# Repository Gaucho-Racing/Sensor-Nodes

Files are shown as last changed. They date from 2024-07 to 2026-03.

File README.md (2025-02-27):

# Sensor Node hardware and software for GR25

---

## Hardware 
The Hardware is split into a couple of folders and have Kicad projects that relate to the Sensor Nodes. This includes random projects and some hardware that might have been usefull.

---

## Software

Includes software for the Sensor Nodes

### Compilation:

To compile and be able to debug the project you need the following: 
- CMAKE 
- arm-none-eabi-gcc
- openocd
- ninja
- VSCode CMAKE extension
- VSCode Cortex Debug extension

**Make sure cmake, arm tolchian, openocd,and ninja are added to path**

To check the version run: 
- cmake --version
- arm-none-eabi-gcc --version
- openocd --version
- ninja --version

After everything is installed you should be able to follow the VSCode UI to compile and debug.

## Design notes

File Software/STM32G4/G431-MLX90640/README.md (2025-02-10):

See the [git wiki page](https://wiki.gauchoracing.com/books/onboarding/page/git) for a primer on git
# Required stuff
## Applications
Mac and Unix download using package managers (besides arm-toolchain), Windows use links below
* [CMAKE](https://cmake.org/download/)  
* [ARM toolchain (arm-none-eabi), CHECK OS VERSION BEFORE DOWNLOADING](https://developer.arm.com/downloads/-/arm-gnu-toolchain-downloads)  
* [openocd](https://github.com/openocd-org/openocd/releases/tag/v0.12.0)  
* [ninja](https://github.com/ninja-build/ninja/releases)  
## VS Code extensions
* CMAKE  
* Cortex Debug
### Optional VS Code extensions
* Serial Monitor

# How to run
1. Download Required stuff and add to PATH
2. Open VSCode  
3. If the CMake Extension prompts you to set up the configuration, choose DEBUG and proceed to step 5
4. Generate the build stuff with `cmake --preset <target>`. With target in development being `Debug` typically.  
5. Run and Debug, Debug using the provided Debug config, Cortex Debug  
6. Cry as nothing works, then after much debugging rejoice as something works!

# Debugging
If something doesn't work chances are one of the tools wasn't added to path correctly, run each of the tools independently  
* CMAKE - `cmake --version`
* ARM toolchain - `arm-none-eabi-gcc --version`
* openocd - `openocd --version`
* ninja - `ninja --version`

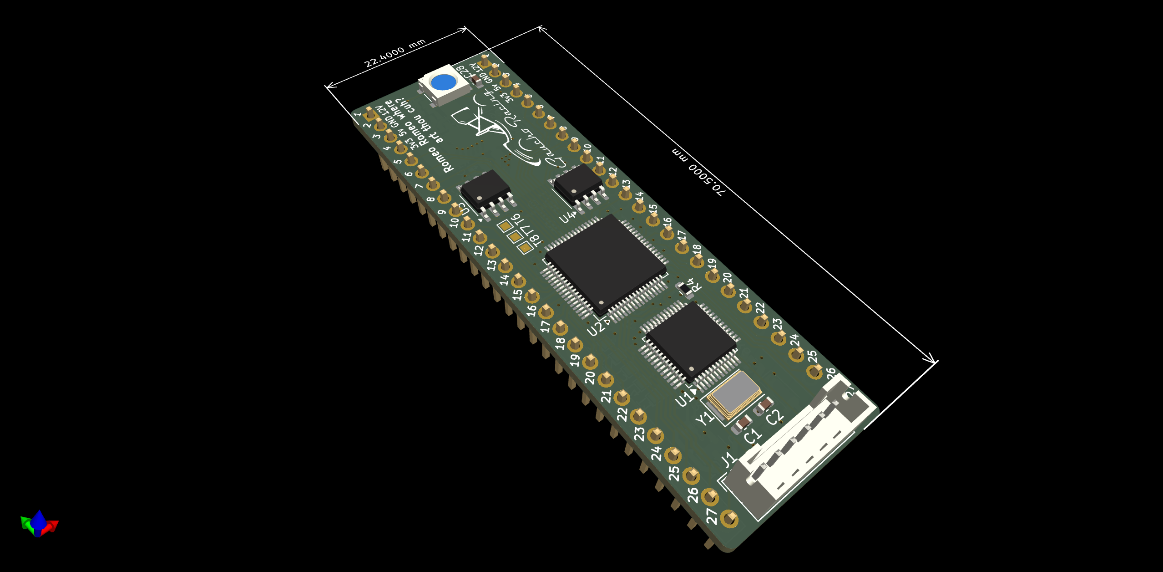
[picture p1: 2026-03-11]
Hardware/Sensor_Nodes_V3/gr25_nodes.png

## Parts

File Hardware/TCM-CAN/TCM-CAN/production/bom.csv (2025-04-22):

Designator | Footprint | Quantity | Value | LCSC Part #
J2, J3 | PinHeader_1x27_P2.54mm_Vertical | 2 | Conn_01x27_Socket
J4 | PinSocket_2x20_P2.54mm_Vertical | 1 | Conn_02x20_Odd_Even
J5 | JST_XH_B6B-XH-A_1x06_P2.50mm_Vertical | 1 | Conn_01x06_Socket

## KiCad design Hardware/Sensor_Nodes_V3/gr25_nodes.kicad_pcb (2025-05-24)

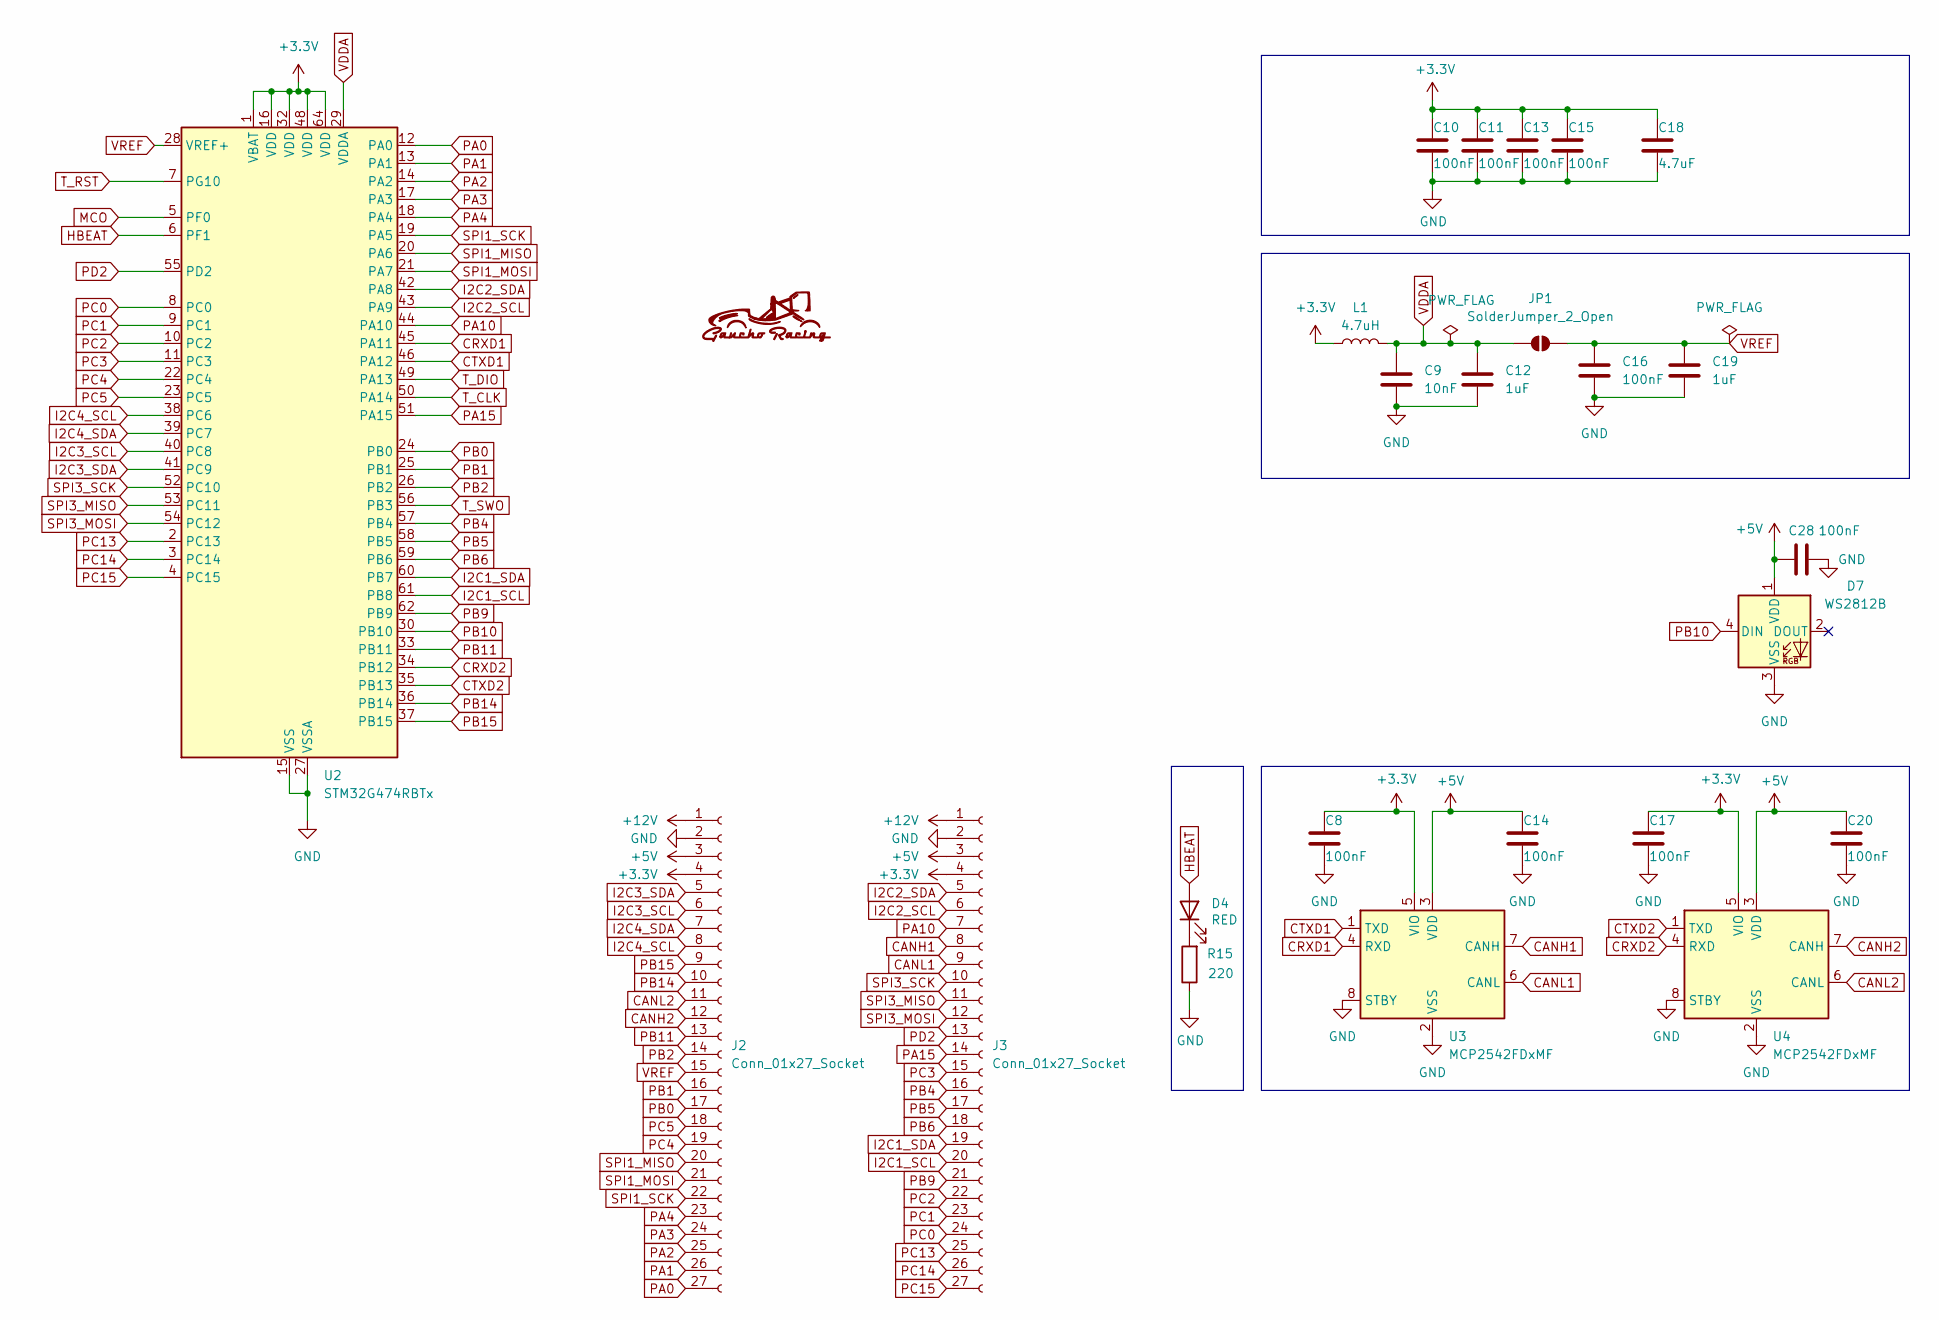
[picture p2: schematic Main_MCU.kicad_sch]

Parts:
C8, C10, C11, C13, C14, C15, C16, C17, C20: 100nF; C_0603_1608Metric; LCSC C14663
C9: 10nF; C_0603_1608Metric; LCSC C57112
C12, C19: 1uF; C_0603_1608Metric; LCSC C15849
C18: 4.7uF; C_0603_1608Metric; LCSC C19666
C28: 100nF; C_0603_1608Metric
D4: RED; LED_0603_1608Metric; LCSC C2286
D7: WS2812B; LED_WS2812B_PLCC4_5.0x5.0mm_P3.2mm
J2, J3: Conn_01x27_Socket; PinHeader_1x27_P2.54mm_Vertical
JP1: SolderJumper_2_Open; SolderJumper-2_P1.3mm_Open_TrianglePad1.0x1.5mm
L1: 4.7uH; C_1206_3216Metric; LCSC C1049
R15: 220; R_0402_1005Metric; LCSC C25091
U2: STM32G474RBTx; LQFP-64_10x10mm_P0.5mm; LCSC C529413
U3, U4: MCP2542FDxMF; SOIC-8_3.9x4.9mm_P1.27mm

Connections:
+3.3V: C8.1, C10.1, C11.1, C13.1, C15.1, C17.1, C18.1, J2.4, J3.4, L1.1, U2.1 (VBAT), U2.16 (VDD), U2.32 (VDD), U2.48 (VDD), U2.64 (VDD), U3.5 (VIO), U4.5 (VIO); also elsewhere on the board
+5V: C14.1, C20.1, C28.2, D7.1 (VDD), J2.3, J3.3, U3.3 (VDD), U4.3 (VDD); also elsewhere on the board
+12V: J2.1, J3.1; also elsewhere on the board
CANH1: J3.8, U3.7 (CANH)
CANH2: J2.12, U4.7 (CANH)
CANL1: J3.9, U3.6 (CANL)
CANL2: J2.11, U4.6 (CANL)
CRXD1: U2.45 (PA11), U3.4 (RXD)
CRXD2: U2.34 (PB12), U4.4 (RXD)
CTXD1: U2.46 (PA12), U3.1 (TXD)
CTXD2: U2.35 (PB13), U4.1 (TXD)
GND: C8.2, C9.2, C10.2, C11.2, C12.2, C13.2, C14.2, C15.2, C16.2, C17.2, C18.2, C19.2, C20.2, C28.1, D7.3 (VSS), J2.2, J3.2, R15.1, U2.15 (VSS), U2.27 (VSSA), U2.31 (VSS), U2.47 (VSS), U2.63 (VSS), U3.2 (VSS), U3.8 (STBY), U3.9 (VSS), U4.2 (VSS), U4.8 (STBY), U4.9 (VSS); also elsewhere on the board
HBEAT: D4.2 (A), U2.6 (PF1)
I2C1_SCL: J3.20, U2.61 (PB8)
I2C1_SDA: J3.19, U2.60 (PB7)
I2C2_SCL: J3.6, U2.43 (PA9)
I2C2_SDA: J3.5, U2.42 (PA8)
I2C3_SCL: J2.6, U2.40 (PC8)
I2C3_SDA: J2.5, U2.41 (PC9)
I2C4_SCL: J2.8, U2.38 (PC6)
I2C4_SDA: J2.7, U2.39 (PC7)
MCO: U2.5 (PF0); also elsewhere on the board
unnamed: D4.1 (K), R15.2
PA0: J2.27, U2.12 (PA0)
PA1: J2.26, U2.13 (PA1)
PA2: J2.25, U2.14 (PA2)
PA3: J2.24, U2.17 (PA3)
PA4: J2.23, U2.18 (PA4)
PA10: J3.7, U2.44 (PA10)
PA15: J3.14, U2.51 (PA15)
PB0: J2.17, U2.24 (PB0)
PB1: J2.16, U2.25 (PB1)
PB2: J2.14, U2.26 (PB2)
PB4: J3.16, U2.57 (PB4)
PB5: J3.17, U2.58 (PB5)
PB6: J3.18, U2.59 (PB6)
PB9: J3.21, U2.62 (PB9)
PB10: D7.4 (DIN), U2.30 (PB10)
PB11: J2.13, U2.33 (PB11)
PB14: J2.10, U2.36 (PB14)
PB15: J2.9, U2.37 (PB15)
PC0: J3.24, U2.8 (PC0)
PC1: J3.23, U2.9 (PC1)
PC2: J3.22, U2.10 (PC2)
PC3: J3.15, U2.11 (PC3)
PC4: J2.19, U2.22 (PC4)
PC5: J2.18, U2.23 (PC5)
PC13: J3.25, U2.2 (PC13)
PC14: J3.26, U2.3 (PC14)
PC15: J3.27, U2.4 (PC15)
PD2: J3.13, U2.55 (PD2)
SPI1_MISO: J2.20, U2.20 (PA6)
SPI1_MOSI: J2.21, U2.21 (PA7)
SPI1_SCK: J2.22, U2.19 (PA5)
SPI3_MISO: J3.11, U2.53 (PC11)
SPI3_MOSI: J3.12, U2.54 (PC12)
SPI3_SCK: J3.10, U2.52 (PC10)
T_CLK: U2.50 (PA14); also elsewhere on the board
T_DIO: U2.49 (PA13); also elsewhere on the board
T_RST: U2.7 (PG10); also elsewhere on the board
T_SWO: U2.56 (PB3); also elsewhere on the board
VDDA: C9.1, C12.1, JP1.1 (A), L1.2, U2.29 (VDDA)
VREF: C16.1, C19.1, J2.15, JP1.2 (B), U2.28 (VREF+)

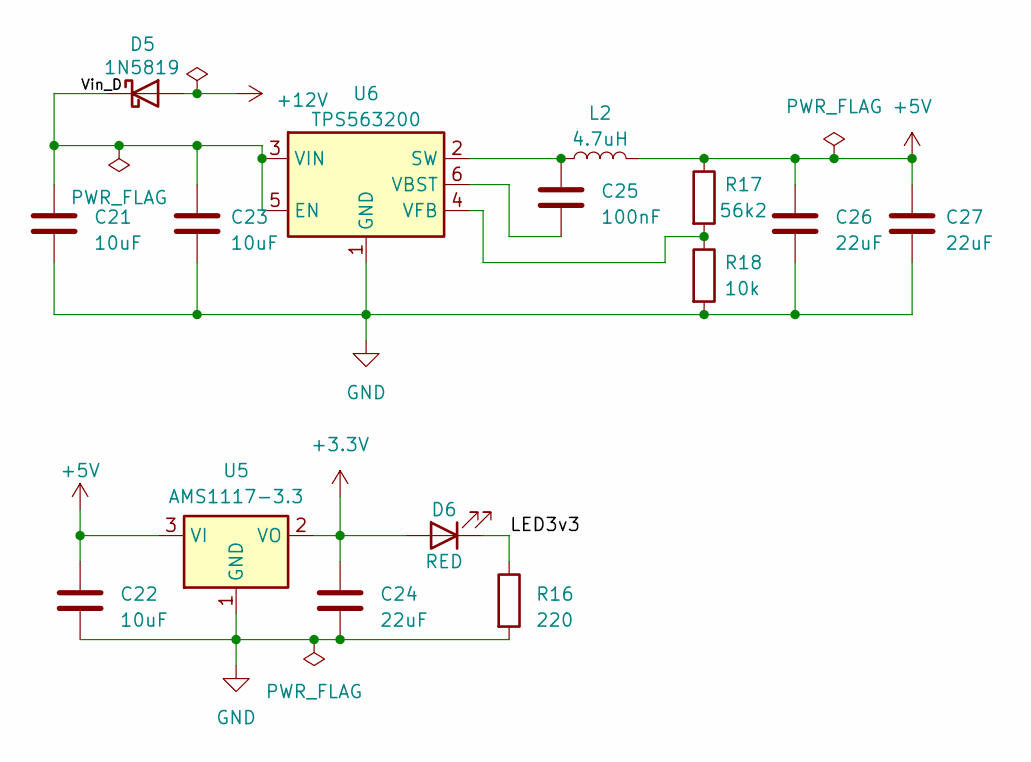
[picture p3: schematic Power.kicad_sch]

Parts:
C21, C22, C23: 10uF; C_0805_2012Metric; LCSC C15850
C24, C26, C27: 22uF; C_0805_2012Metric; LCSC C45783
C25: 100nF; C_0603_1608Metric; LCSC C14663
D5: 1N5819; D_SOD-323_HandSoldering; LCSC C191023
D6: RED; LED_0603_1608Metric; LCSC C2286
L2: 4.7uH; L_Cenker_CKCS6020; LCSC C5291878
R16: 220; R_0402_1005Metric; LCSC C25091
R17: 56k2; R_0402_1005Metric; LCSC C25796
R18: 10k; R_0402_1005Metric; LCSC C25744
U5: AMS1117-3.3; SOT-223-3_TabPin2; LCSC C6186
U6: TPS563200; SOT-23-6; LCSC C97253

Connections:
+3.3V: C24.1, D6.2 (A), U5.2 (VO); also elsewhere on the board
+5V: C22.1, C26.1, C27.1, L2.2, R17.1, U5.3 (VI); also elsewhere on the board
+12V: D5.2 (A); also elsewhere on the board
/Power/LED3v3: D6.1 (K), R16.1
/Power/Vin_D: C21.1, C23.1, D5.1 (K), U6.3 (VIN), U6.5 (EN)
GND: C21.2, C22.2, C23.2, C24.2, C26.2, C27.2, R16.2, R18.2, U5.1 (GND), U6.1 (GND); also elsewhere on the board
unnamed: C25.1, L2.1, U6.2 (SW)
unnamed: C25.2, U6.6 (VBST)
unnamed: R17.2, R18.1, U6.4 (VFB)

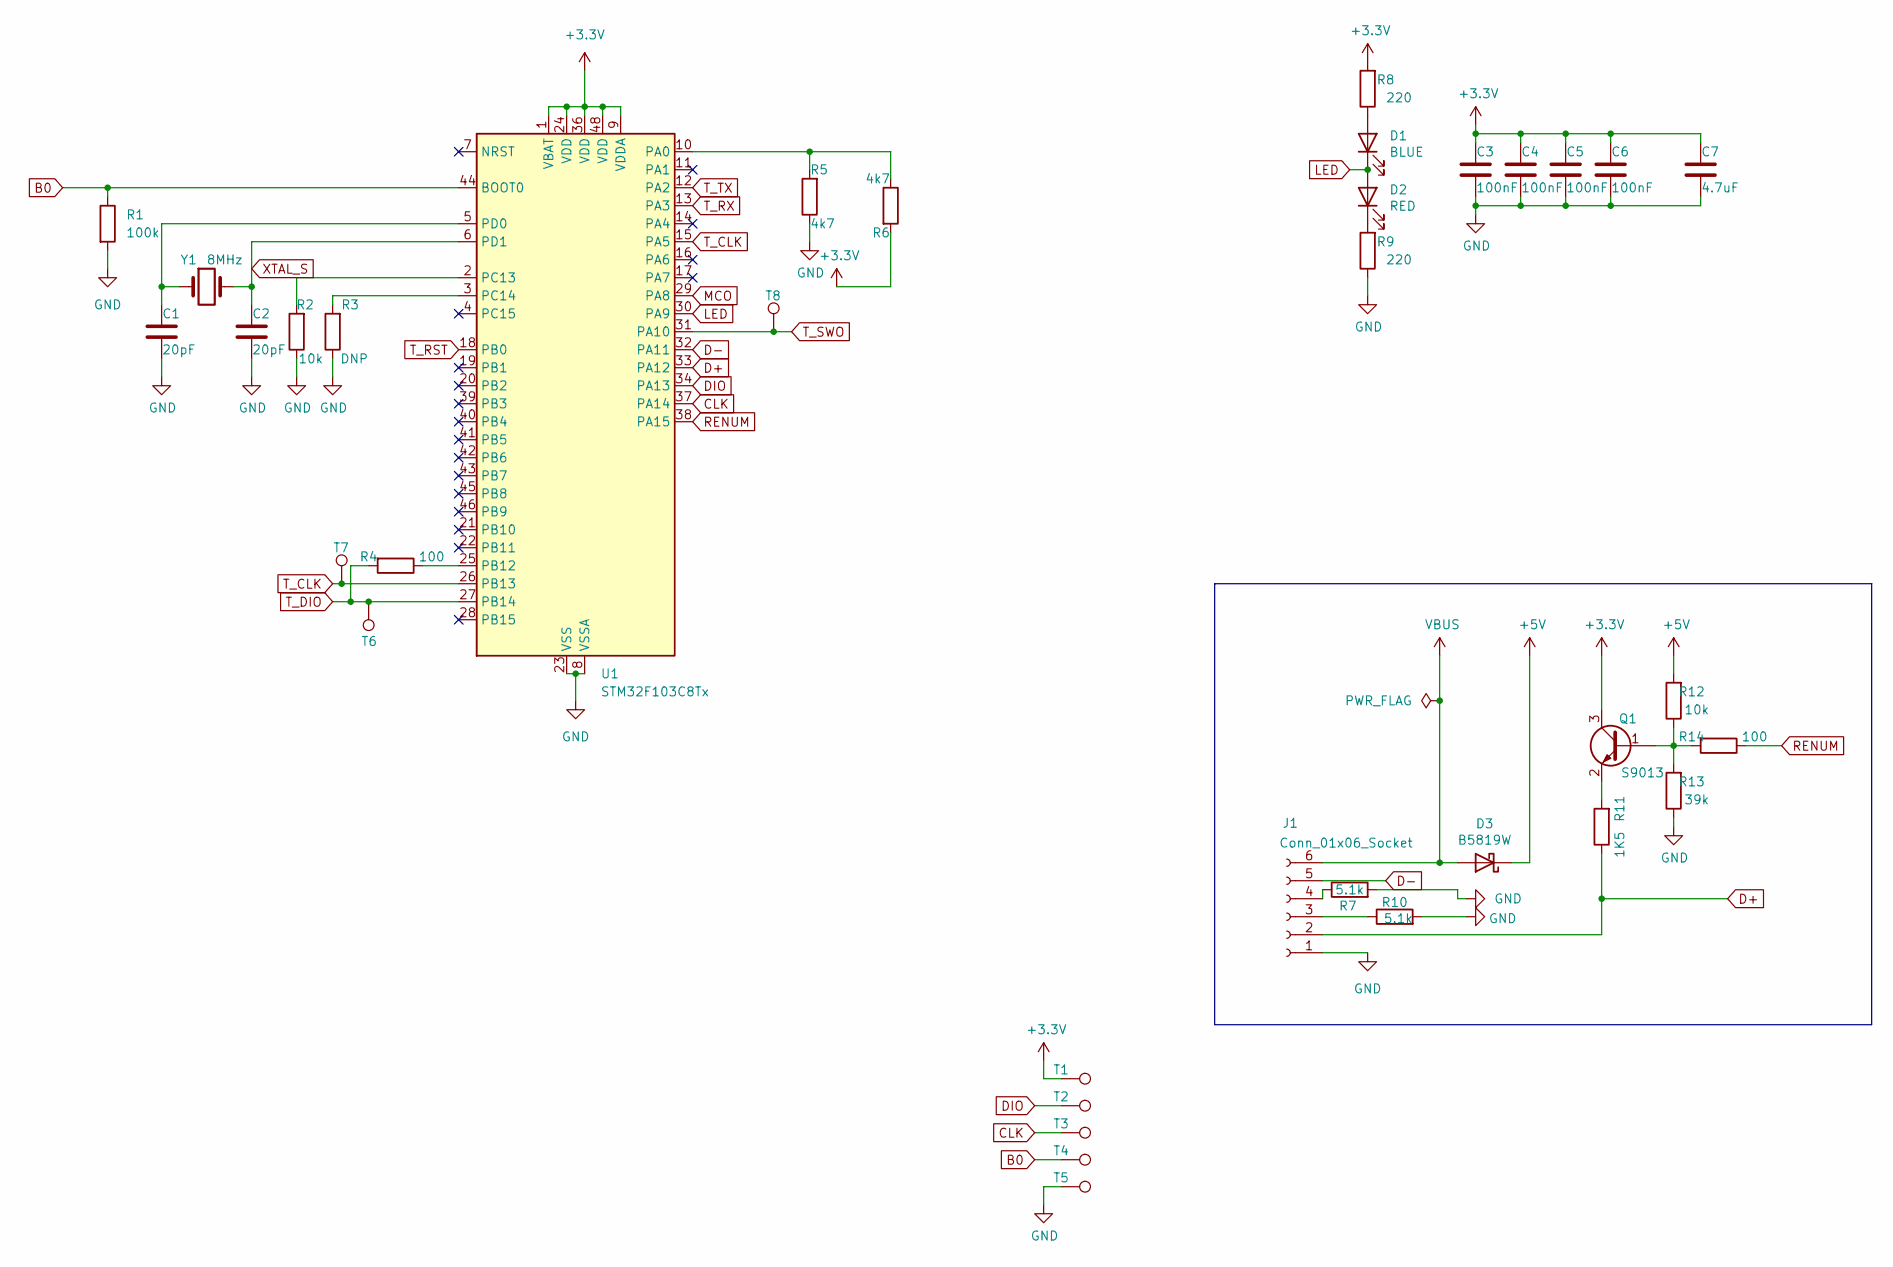
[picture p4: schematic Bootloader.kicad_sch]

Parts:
C1, C2: 20pF; C_0603_1608Metric; LCSC C1648
C3, C4, C5, C6: 100nF; C_0603_1608Metric; LCSC C14663
C7: 4.7uF; C_0603_1608Metric; LCSC C19666
D1: BLUE; LED_0603_1608Metric; LCSC C2290
D2: RED; LED_0603_1608Metric; LCSC C2286
D3: B5819W; D_SOD-123; LCSC C8598
J1: Conn_01x06_Socket; JST_PH_B6B-PH-K_1x06_P2.00mm_Vertical
Q1: S9013; SOT-23; LCSC C6749
R1: 100k; R_0402_1005Metric; LCSC C25741
R2, R12: 10k; R_0402_1005Metric; LCSC C25744
R3: DNP; R_0402_1005Metric; LCSC xxC25744
R4: 100; R_0603_1608Metric; LCSC C22775
R5, R6: 4k7; R_0402_1005Metric; LCSC C25900
R7, R10: 5.1k; R_0402_1005Metric; LCSC C25905
R8, R9: 220; R_0402_1005Metric; LCSC C25091
R11: 1K5; R_0402_1005Metric; LCSC C25867
R13: 39k; R_0402_1005Metric; LCSC C25783
R14: 100; R_0402_1005Metric; LCSC C25076
T1, T2, T3, T4, T5, T6, T7, T8: TestPoint_Pad_1.0x1.0mm
U1: STM32F103C8Tx; LQFP-48_7x7mm_P0.5mm; LCSC C8734
Y1: 8MHz; Crystal_SMD_5032-2Pin_5.0x3.2mm; LCSC C115962

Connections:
+3.3V: C3.1, C4.1, C5.1, C6.1, C7.1, Q1.3 (C), R6.2, R8.2, T1.1, U1.1 (VBAT), U1.9 (VDDA), U1.24 (VDD), U1.36 (VDD), U1.48 (VDD); also elsewhere on the board
+5V: D3.1 (K), R12.2; also elsewhere on the board
B0: R1.1, T4.1, U1.44 (BOOT0)
CLK: T3.1, U1.37 (PA14)
D+: J1.2, R11.1, U1.33 (PA12)
D-: J1.5, U1.32 (PA11)
DIO: T2.1, U1.34 (PA13)
GND: C1.2, C2.2, C3.2, C4.2, C5.2, C6.2, C7.2, J1.1, R1.2, R2.1, R3.1, R5.1, R7.2, R9.1, R10.2, R13.1, T5.1, U1.8 (VSSA), U1.23 (VSS), U1.35 (VSS), U1.47 (VSS); also elsewhere on the board
LED: D1.1 (K), D2.2 (A), U1.30 (PA9)
MCO: U1.29 (PA8); also elsewhere on the board
unnamed: D1.2 (A), R8.1
unnamed: D2.1 (K), R9.2
unnamed: J1.3, R10.1
unnamed: J1.4, R7.1
unnamed: Q1.1 (B), R12.1, R13.2, R14.2
unnamed: Q1.2 (E), R11.2
unnamed: R5.2, R6.1, U1.10 (PA0)
unnamed: R4.1, U1.25 (PB12)
unnamed: R2.2, U1.2 (PC13)
unnamed: R3.2, U1.3 (PC14)
unnamed: C1.1, U1.5 (PD0), Y1.1
RENUM: R14.1, U1.38 (PA15)
T_CLK: T7.1, U1.15 (PA5), U1.26 (PB13); also elsewhere on the board
T_DIO: R4.2, T6.1, U1.27 (PB14); also elsewhere on the board
T_RST: U1.18 (PB0); also elsewhere on the board
T_RX: U1.13 (PA3)
T_SWO: T8.1, U1.31 (PA10); also elsewhere on the board
T_TX: U1.12 (PA2)
VBUS: D3.2 (A), J1.6
XTAL_S: C2.1, U1.6 (PD1), Y1.2

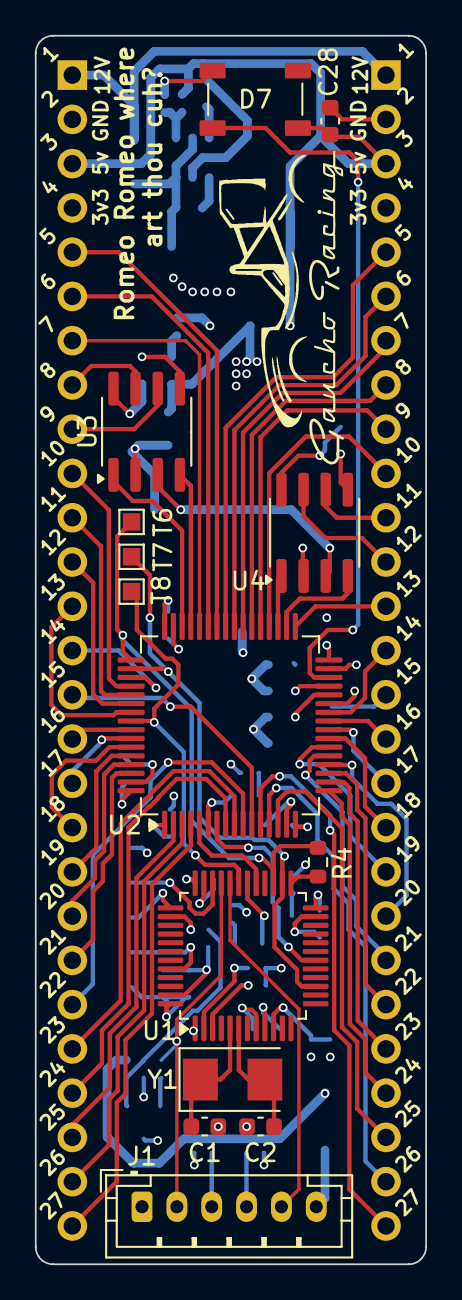
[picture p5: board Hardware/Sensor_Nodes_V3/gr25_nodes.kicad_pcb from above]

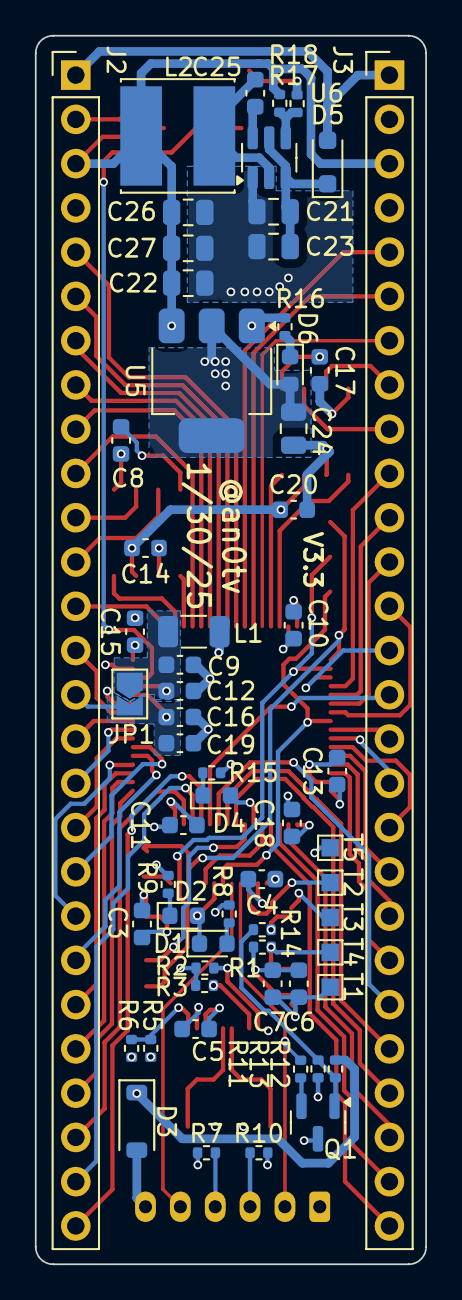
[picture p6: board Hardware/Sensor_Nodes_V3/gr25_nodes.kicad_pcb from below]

Board: 4 copper layers, 22.4 x 70.5 mm, 75 parts (61 on the bottom side), 88 nets.

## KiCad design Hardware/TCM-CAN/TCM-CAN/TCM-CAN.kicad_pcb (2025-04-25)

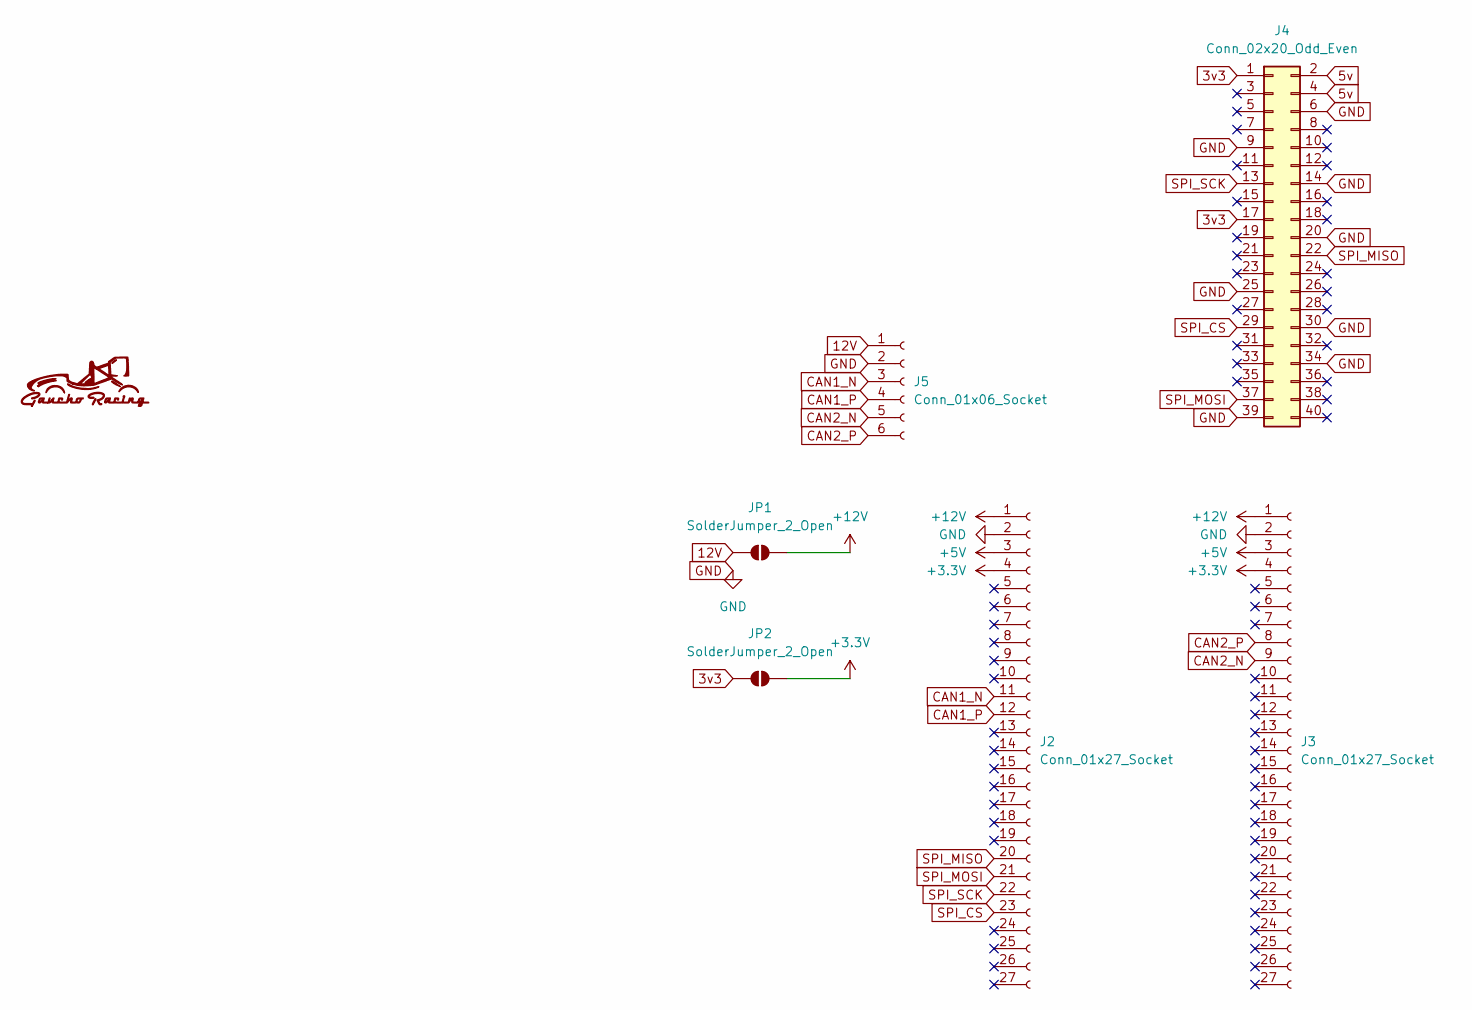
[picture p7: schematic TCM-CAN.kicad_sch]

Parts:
J2, J3: Conn_01x27_Socket; PinHeader_1x27_P2.54mm_Vertical
J4: Conn_02x20_Odd_Even; PinSocket_2x20_P2.54mm_Vertical
J5: Conn_01x06_Socket; JST_XH_B6B-XH-A_1x06_P2.50mm_Vertical
JP1, JP2: SolderJumper_2_Open; SolderJumper-2_P1.3mm_Open_Pad1.0x1.5mm

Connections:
3v3: J4.1, J4.17, JP2.1 (A)
5v: J4.2, J4.4
12V: J5.1, JP1.1 (A)
+3.3V: J2.4, J3.4, JP2.2 (B)
+5V: J2.3, J3.3
+12V: J2.1, J3.1, JP1.2 (B)
CAN1_N: J2.11, J5.3
CAN1_P: J2.12, J5.4
CAN2_N: J3.9, J5.5
CAN2_P: J3.8, J5.6
GND: J2.2, J3.2, J4.6, J4.9, J4.14, J4.20, J4.25, J4.30, J4.34, J4.39, J5.2
SPI_CS: J2.23, J4.29
SPI_MISO: J2.20, J4.22
SPI_MOSI: J2.21, J4.37
SPI_SCK: J2.22, J4.13

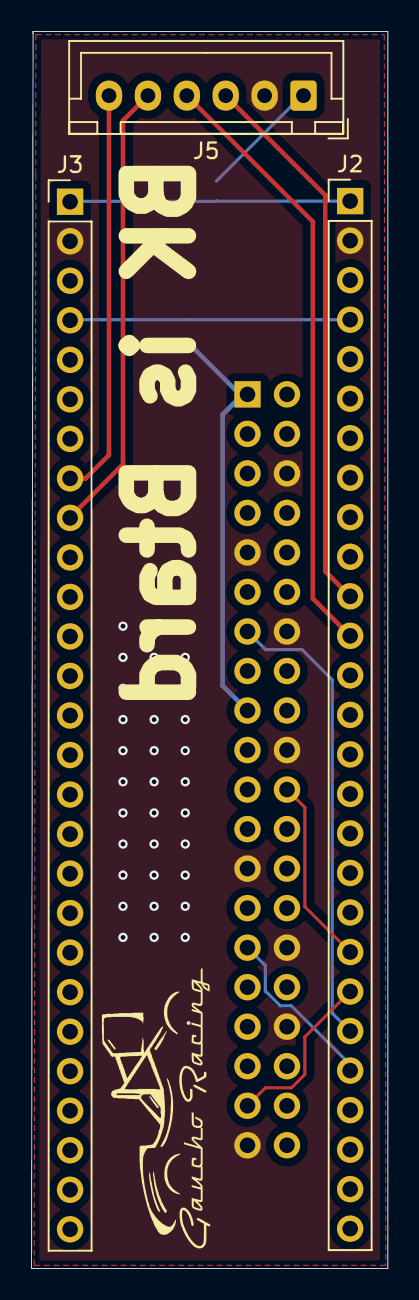
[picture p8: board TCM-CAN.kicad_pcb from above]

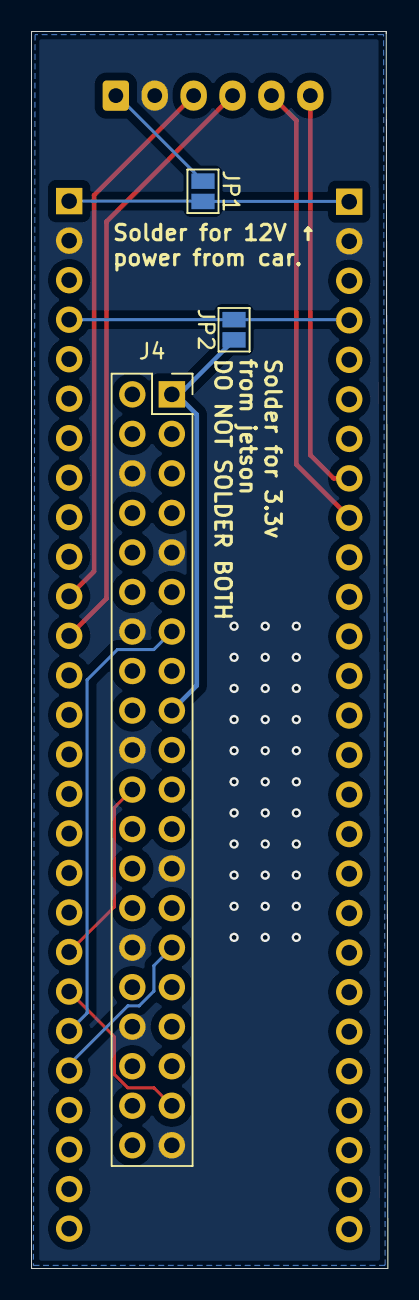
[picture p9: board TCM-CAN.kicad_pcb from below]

Board: 2 copper layers, 22.9 x 79.5 mm, 6 parts (3 on the bottom side), 15 nets.

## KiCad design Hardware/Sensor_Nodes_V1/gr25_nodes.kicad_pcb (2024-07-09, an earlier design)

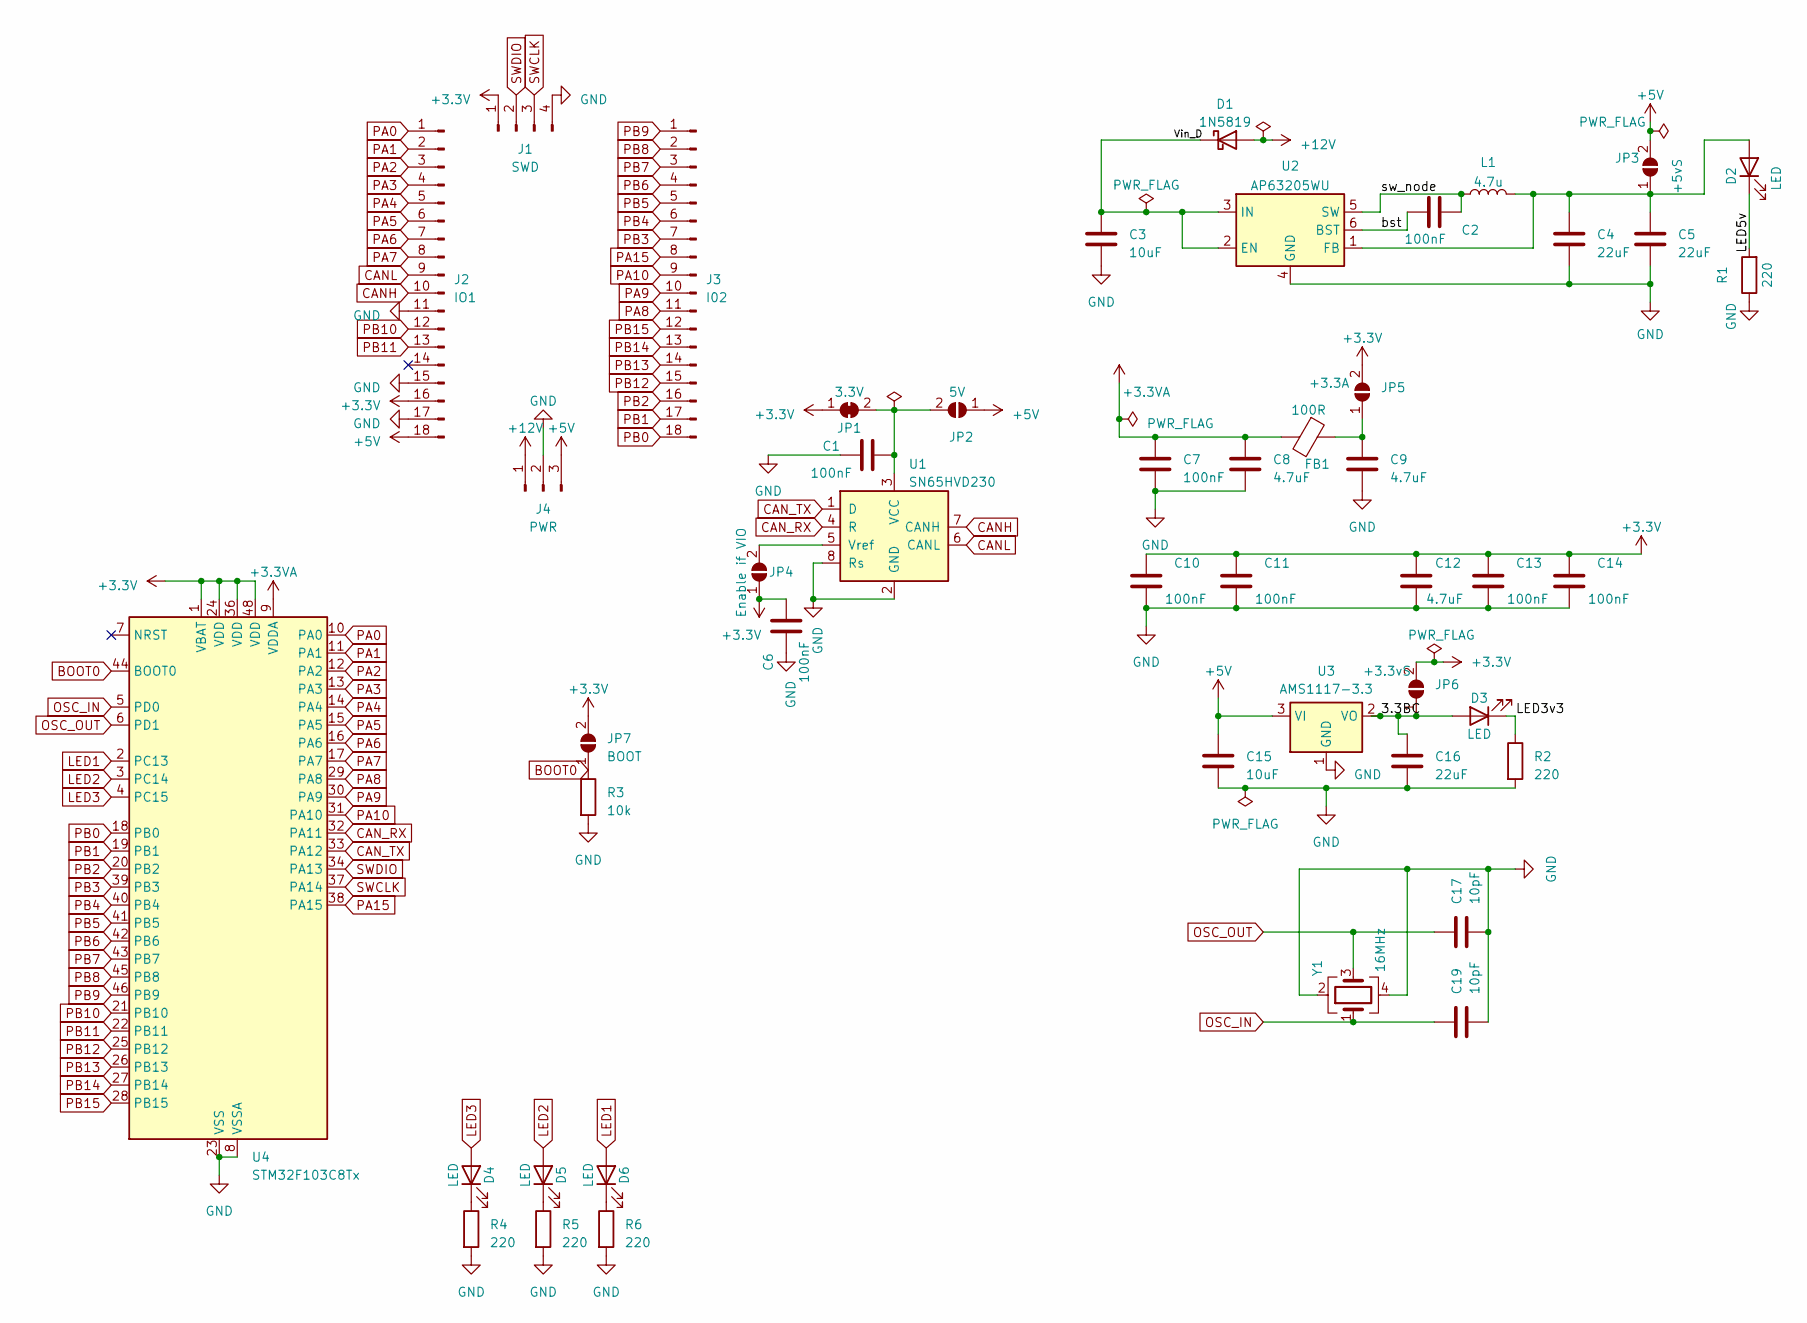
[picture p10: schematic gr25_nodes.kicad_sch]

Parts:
C1, C2, C6, C7, C10, C11, C13, C14: 100nF; C_0603_1608Metric; LCSC C14663
C3: 10uF; C_0805_2012Metric; LCSC C440198
C4, C5, C16: 22uF; C_1206_3216Metric; LCSC C12891
C8, C9, C12: 4.7uF; C_0603_1608Metric; LCSC C19666
C15: 10uF; C_0603_1608Metric; LCSC C96446
C17, C19: 10pF; C_0603_1608Metric; LCSC C1634
D1: 1N5819; D_SOD-323_HandSoldering; LCSC C191023
D2, D3, D4, D5, D6: LED; D_0603_1608Metric; LCSC C2286
FB1: 100R; L_0805_2012Metric; LCSC C1015
J1: SWD; PinHeader_1x04_P2.54mm_Vertical
J2: IO1; PinHeader_1x18_P2.54mm_Vertical
J3: I02; PinHeader_1x18_P2.54mm_Vertical
J4: PWR; PinHeader_1x03_P2.54mm_Vertical
JP1: 3.3V; SolderJumper-2_P1.3mm_Bridged_RoundedPad1.0x1.5mm
JP2: 5V; SolderJumper-2_P1.3mm_Open_RoundedPad1.0x1.5mm
JP3: +5vS; SolderJumper-2_P1.3mm_Open_RoundedPad1.0x1.5mm
JP4: Enable if VIO; SolderJumper-2_P1.3mm_Open_RoundedPad1.0x1.5mm
JP5: +3.3A; SolderJumper-2_P1.3mm_Open_RoundedPad1.0x1.5mm
JP6: +3.3vS; SolderJumper-2_P1.3mm_Open_RoundedPad1.0x1.5mm
JP7: BOOT; SolderJumper-2_P1.3mm_Open_RoundedPad1.0x1.5mm
L1: 4.7u; L_Bourns-SRN4018; PARTNUM SRN4018-4R7M
R1, R2, R4, R5, R6: 220; R_0603_1608Metric; LCSC C22962
R3: 10k; R_0603_1608Metric; LCSC C25804
U1: SN65HVD230; SOIC-8_3.9x4.9mm_P1.27mm; LCSC C12084
U2: AP63205WU; TSOT-23-6; PARTNUM AP63205WU
U3: AMS1117-3.3; SOT-223-3_TabPin2; LCSC C6186
U4: STM32F103C8Tx; LQFP-48_7x7mm_P0.5mm; LCSC C8734
Y1: 16MHz; Crystal_SMD_3225-4Pin_3.2x2.5mm; LCSC C13738

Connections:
+3.3V: C6.1, C10.1, C11.1, C12.1, C13.1, C14.1, J1.1, J2.16, JP1.1 (A), JP4.1 (A), JP5.2 (B), JP6.2 (B), JP7.2 (B), U4.1 (VBAT), U4.24 (VDD), U4.36 (VDD), U4.48 (VDD)
+3.3VA: C7.1, C8.1, FB1.2, U4.9 (VDDA)
+5V: C15.1, J2.18, J4.3, JP2.1 (A), JP3.2 (B), U3.3 (VI)
+12V: D1.2 (A), J4.1
/3.3BC: C16.1, D3.2 (A), JP6.1 (A), U3.2 (VO)
/LED3v3: D3.1 (K), R2.1
/LED5v: D2.1 (K), R1.2
/Vin_D: C3.1, D1.1 (K), U2.2 (EN), U2.3 (IN)
/bst: C2.1, U2.6 (BST)
/sw_node: C2.2, L1.1, U2.5 (SW)
BOOT0: JP7.1 (A), R3.1, U4.44 (BOOT0)
CANH: J2.10, U1.7 (CANH)
CANL: J2.9, U1.6 (CANL)
CAN_RX: U1.4 (R), U4.32 (PA11)
CAN_TX: U1.1 (D), U4.33 (PA12)
GND: C1.2, C3.2, C4.2, C5.2, C6.2, C7.2, C8.2, C9.2, C10.2, C11.2, C12.2, C13.2, C14.2, C15.2, C16.2, C17.2, C19.2, J1.4, J2.11, J2.15, J2.17, J4.2, R1.1, R2.2, R3.2, R4.2, R5.2, R6.2, U1.2 (GND), U1.8 (Rs), U2.4 (GND), U3.1 (GND), U4.8 (VSSA), U4.23 (VSS), U4.35 (VSS), U4.47 (VSS), Y1.2, Y1.4
LED1: D6.2 (A), U4.2 (PC13)
LED2: D5.2 (A), U4.3 (PC14)
LED3: D4.2 (A), U4.4 (PC15)
unnamed: C1.1, JP1.2 (B), JP2.2 (B), U1.3 (VCC)
unnamed: C4.1, C5.1, D2.2 (A), JP3.1 (A), L1.2, U2.1 (FB)
unnamed: D4.1 (K), R4.1
unnamed: D5.1 (K), R5.1
unnamed: D6.1 (K), R6.1
unnamed: JP4.2 (B), U1.5 (Vref)
unnamed: C9.1, FB1.1, JP5.1 (A)
OSC_IN: C19.1, U4.5 (PD0), Y1.1
OSC_OUT: C17.1, U4.6 (PD1), Y1.3
PA0: J2.1, U4.10 (PA0)
PA1: J2.2, U4.11 (PA1)
PA2: J2.3, U4.12 (PA2)
PA3: J2.4, U4.13 (PA3)
PA4: J2.5, U4.14 (PA4)
PA5: J2.6, U4.15 (PA5)
PA6: J2.7, U4.16 (PA6)
PA7: J2.8, U4.17 (PA7)
PA8: J3.11, U4.29 (PA8)
PA9: J3.10, U4.30 (PA9)
PA10: J3.9, U4.31 (PA10)
PA15: J3.8, U4.38 (PA15)
PB0: J3.18, U4.18 (PB0)
PB1: J3.17, U4.19 (PB1)
PB2: J3.16, U4.20 (PB2)
PB3: J3.7, U4.39 (PB3)
PB4: J3.6, U4.40 (PB4)
PB5: J3.5, U4.41 (PB5)
PB6: J3.4, U4.42 (PB6)
PB7: J3.3, U4.43 (PB7)
PB8: J3.2, U4.45 (PB8)
PB9: J3.1, U4.46 (PB9)
PB10: J2.12, U4.21 (PB10)
PB11: J2.13, U4.22 (PB11)
PB12: J3.15, U4.25 (PB12)
PB13: J3.14, U4.26 (PB13)
PB14: J3.13, U4.27 (PB14)
PB15: J3.12, U4.28 (PB15)
SWCLK: J1.3, U4.37 (PA14)
SWDIO: J1.2, U4.34 (PA13)

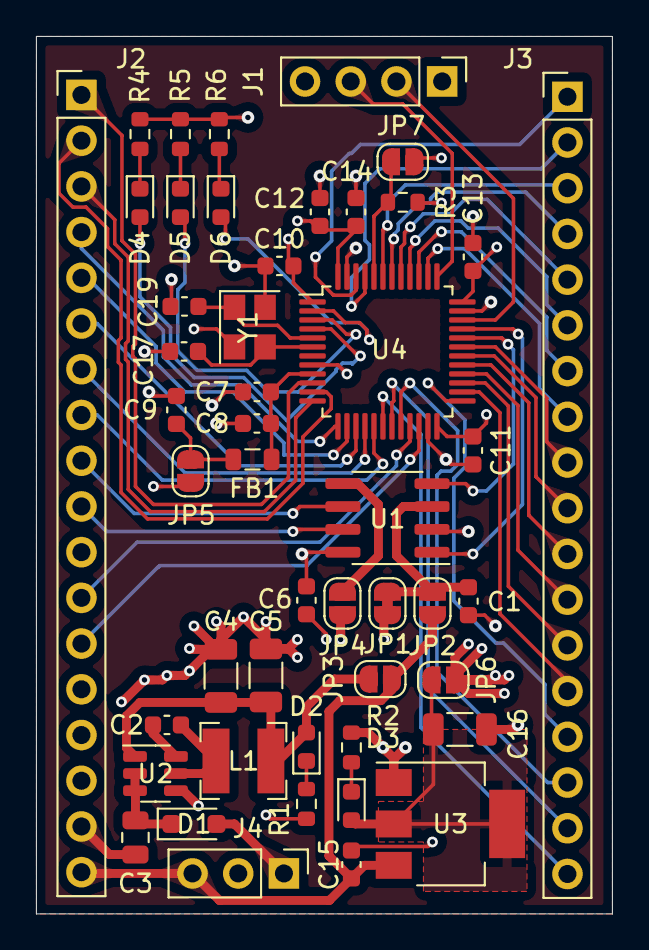
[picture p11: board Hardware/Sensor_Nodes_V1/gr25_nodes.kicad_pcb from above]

Board: 4 copper layers, 32.0 x 48.8 mm, 48 parts (0 on the bottom side), 58 nets.

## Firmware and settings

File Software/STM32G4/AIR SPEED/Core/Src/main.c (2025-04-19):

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
/* Includes ------------------------------------------------------------------*/
#include "main.h"
#include "crc.h"
#include "fdcan.h"
#include "i2c.h"
#include "spi.h"
#include "gpio.h"


/* USER CODE BEGIN Includes */
#include <stdio.h>
#include <math.h>
// #include "VL53L4ED_api.h"
#include "Aspeed.h"
//#include "circularBuffer.h"
/* USER CODE END Includes */

/* USER CODE BEGIN PD */
#ifdef __GNUC__
#define PUTCHAR_PROTOTYPE int __io_putchar(int ch)
#else
#define PUTCHAR_PROTOTYPE int fputc(int ch, FILE *f)
#endif
/* USER CODE END PD */

/* USER CODE BEGIN PM */
PUTCHAR_PROTOTYPE
{
  ITM_SendChar(ch);
  return ch;
}
//CircularBuffer *cb;
/* USER CODE END PM */


/* USER CODE BEGIN PV */
// FDCAN_RxHeaderTypeDef RxHeader_FDCAN2;
/* USER CODE END PV */

void SystemClock_Config(void);
/* USER CODE BEGIN 0 */
/*
I2C2 - is meant for thermal sensor MLX90640 and is ran using DMA to offload CPU for calculations
     - still need to fully test but ideally implmentation is done


 */
/* USER CODE END 0 */

/**
  * @brief  The application entry point.
  * @retval int
  */
int main(void)
{

  /* USER CODE BEGIN 1 */
  //cb = circular_buffer_init(64, 68 * sizeof(uint8_t));
  /* USER CODE END 1 */

  /* MCU Configuration--------------------------------------------------------*/

  /* Reset of all peripherals, Initializes the Flash interface and the Systick. */
  HAL_Init();

  /* Configure the system clock */
  SystemClock_Config();

  /* Initialize all configured peripherals */
  MX_GPIO_Init();
  MX_CRC_Init();
  MX_FDCAN1_Init();
  MX_FDCAN2_Init();
  MX_I2C1_Init();
  MX_SPI3_Init();
  /* USER CODE BEGIN 2 */
  
  // HAL_FDCAN_Start(&hfdcan1);
  // HAL_FDCAN_Start(&hfdcan2);
  // HAL_FDCAN_ActivateNotification(&hfdcan1, FDCAN_IT_RX_FIFO0_NEW_MESSAGE, 0);
  // HAL_FDCAN_ActivateNotification(&hfdcan2, FDCAN_IT_RX_FIFO0_NEW_MESSAGE, 0);

  
  // static uint16_t eeMLX90640[832];
  // static paramsMLX90640 mlx90640;
  // #define MLX90640_ADDRESS 0x33<<1
  // MLX90640_DumpEE(MLX90640_ADDRESS, eeMLX90640);
  
  // MLX90640_ExtractParameters(eeMLX90640, &mlx90640);
  
  // MLX90640_SetRefreshRate(MLX90640_ADDRESS, 0x05);

  // MLX90640_SynchFrame(MLX90640_ADDRESS);
  //  MLX90640_SetRefreshRate(0x33, 0x05);
  /* USER CODE END 2 */

  /* Infinite loop */
  /* USER CODE BEGIN WHILE */
  HAL_GPIO_WritePin(GPIOB, GPIO_PIN_1, GPIO_PIN_RESET); //TOF_L_XSHUT_Pin
  HAL_GPIO_WritePin(GPIOF, GPIO_PIN_1, GPIO_PIN_RESET); //TOF_C_XSHUT_Pin
  HAL_Delay(100); // wait for 5ms to reset the device
  HAL_GPIO_WritePin(GPIOB, GPIO_PIN_1, GPIO_PIN_SET); //TOF_L_XSHUT_Pin
  HAL_GPIO_WritePin(GPIOF, GPIO_PIN_1, GPIO_PIN_SET); //TOF_C_XSHUT_Pin
  HAL_Delay(100); // wait for 5ms to power up the device
  float data[2] = {0};
  

  while (1)
  { 
    // HAL_FDCAN_AddMessageToTxFifoQ(&hfdcan1, &TxHeader, TxData);
    // HAL_FDCAN_AddMessageToTxFifoQ(&hfdcan2, &TxHeader, TxData);
    /* USER CODE END WHILE */

    /* USER CODE BEGIN 3 */
    HAL_Delay(10);
    ASpeedRead(data);
    
    // printf("Pressure * 10000: %d, Temp * 100: %d\n", data[0] + 159, data[1]);
    float air_density = (101693.25)/(287.05*(data[1] + 273.15)); // p/(RT)
    float air_speed = sqrtf((2 * 6894.76 * (fabsf(data[0] + 0.0156f)))/air_density);
    int16_t lazy_air = (int16_t)(air_speed * 100);
    if(data[0] >= 0.0){
      printf("%d\n", (int16_t)(air_speed * 100));
    } else {
      printf("%d\n", -1 * (int16_t)(air_speed * 100));
    }
    // printf("%d\n", lazy_air);
   
    
    
  }
  /* USER CODE END 3 */
}

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
/* USER CODE BEGIN 4 */
// void HAL_FDCAN_RxFifo0Callback(FDCAN_HandleTypeDef *hfdcan, uint32_t RxFifo0ITs)
// {
//   uint8_t RxData[64];
//   HAL_FDCAN_GetRxMessage(hfdcan, FDCAN_RX_FIFO0, &RxHeader_FDCAN2, RxData);
//   printf("got messgae\n");
//   //circularBufferPush(cb, RxData, sizeof(RxData));


// }
/* USER CODE END 4 */

/**
  * @brief  Period elapsed callback in non blocking mode
  * @note   This function is called  when TIM1 interrupt took place, inside
  * HAL_TIM_IRQHandler(). It makes a direct call to HAL_IncTick() to increment
  * a global variable "uwTick" used as application time base.
  * @param  htim : TIM handle
  * @retval None
  */
void HAL_TIM_PeriodElapsedCallback(TIM_HandleTypeDef *htim)
{
  if (htim->Instance == TIM1) {
    HAL_IncTick();
  }
}

/**
  * @brief  This function is executed in case of error occurrence.
  * @retval None
  */
void Error_Handler(void)
{
  /* USER CODE BEGIN Error_Handler_Debug */
  /* User can add his own implementation to report the HAL error return state */
  __disable_irq();
  while (1)
  {
  }
  /* USER CODE END Error_Handler_Debug */
}

#ifdef  USE_FULL_ASSERT
/**
  * @brief  Reports the name of the source file and the source line number
  *         where the assert_param error has occurred.
  * @param  file: pointer to the source file name
  * @param  line: assert_param error line source number
  * @retval None
  */
void assert_failed(uint8_t *file, uint32_t line)
{
  /* USER CODE BEGIN 6 */
  /* User can add his own implementation to report the file name and line number,
     ex: printf("Wrong parameters value: file %s on line %d\r\n", file, line) */
  /* USER CODE END 6 */
}
#endif /* USE_FULL_ASSERT */

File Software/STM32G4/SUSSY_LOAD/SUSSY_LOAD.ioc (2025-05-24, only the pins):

Mcu.UserName=STM32G474RETx
PA0.Signal=ADC1_IN1
PA13.Signal=SYS_JTMS-SWDIO
PA14.Signal=SYS_JTCK-SWCLK
PA5.Signal=SPI1_SCK
PA6.Signal=SPI1_MISO
PA7.Signal=SPI1_MOSI
PB3.Signal=SYS_JTDO-SWO
PF0-OSC_IN.Signal=RCC_OSC_IN
PF1-OSC_OUT.Signal=GPIO_Output

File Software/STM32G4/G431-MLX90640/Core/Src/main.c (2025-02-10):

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
/* Includes ------------------------------------------------------------------*/
#include "main.h"
#include "adc.h"
#include "crc.h"
#include "i2c.h"
#include "gpio.h"

/* USER CODE BEGIN Includes */
#include "MLX90640_API.h"
#include "MLX90640_I2C_Driver.h"
#include <stdio.h>
#include <arm_math.h>
/* USER CODE END Includes */

/* USER CODE BEGIN PTD */
#ifdef __GNUC__
#define PUTCHAR_PROTOTYPE int __io_putchar(int ch)
#else
#define PUTCHAR_PROTOTYPE int fputc(int ch, FILE *f)
#endif
/* USER CODE END PTD */


/* USER CODE BEGIN PV */
/* Buffer used for transmission */
uint8_t aTxBuffer[] = "****SPI - Two Boards communication based on Polling **** SPI Message ******** SPI Message ******** SPI Message ****";

//MLX stuff
float emmissivity = 0.95;
uint16_t MLX90640_address = 0x33;
paramsMLX90640 mlx90640;
static uint16_t eeMLX90640[832];
static uint16_t mlx90640Frame[834];
static float mlx90640To[768];
int status;
float tr;


/* Buffer used for reception */
uint8_t aRxBuffer[BUFFERSIZE];
/* USER CODE END PV */

void SystemClock_Config(void);
/* USER CODE BEGIN PFP */
static uint16_t Buffercmp(uint8_t *pBuffer1, uint8_t *pBuffer2, uint16_t BufferLength);
/* USER CODE END PFP */

/* USER CODE BEGIN 0 */

PUTCHAR_PROTOTYPE
{
  ITM_SendChar(ch);
  return ch;
}

/* USER CODE END 0 */

/**
  * @brief  The application entry point.
  * @retval int
  */
int main(void)
{

  /* USER CODE BEGIN 1 */

  /* STM32G4xx HAL library initialization:
       - Configure the Flash prefetch
       - Systick timer is configured by default as source of time base, but user
         can eventually implement his proper time base source (a general purpose
         timer for example or other time source), keeping in mind that Time base
         duration should be kept 1ms since PPP_TIMEOUT_VALUEs are defined and
         handled in milliseconds basis.
       - Set NVIC Group Priority to 4
       - Low Level Initialization
     */
  /* USER CODE END 1 */

  /* MCU Configuration--------------------------------------------------------*/

  /* Reset of all peripherals, Initializes the Flash interface and the Systick. */
  HAL_Init();

  /* Configure the system clock */
  SystemClock_Config();

  /* Initialize all configured peripherals */
  MX_GPIO_Init();
  MX_ADC1_Init();
  MX_CRC_Init();
  MX_I2C2_Init();
  /* USER CODE BEGIN 2 */

  /* Configure LED2 */
  // BSP_LED_Init(LED2);

  /*##-1- Start the Full Duplex Communication process ########################*/
  /* While the SPI in TransmitReceive process, user can transmit data through
     "aTxBuffer" buffer & receive data through "aRxBuffer" */
  /* Timeout is set to 5S */


    status = MLX90640_SetRefreshRate(MLX90640_address, 0x07);

    status = MLX90640_DumpEE(MLX90640_address, eeMLX90640);
    if(status != 0){
      Error_Handler();
    }

    status = MLX90640_ExtractParameters(eeMLX90640, &mlx90640);
    if(status != 0){
      Error_Handler();
    }



  /* USER CODE END 2 */

  /* Infinite loop */
  /* USER CODE BEGIN WHILE */
  while (1)
  {
   
    status = MLX90640_GetFrameData(MLX90640_address, mlx90640Frame);
    if(status != 0){
      Error_Handler();
    }
    tr = MLX90640_GetTa(mlx90640Frame, &mlx90640);
    MLX90640_CalculateTo(mlx90640Frame, &mlx90640, emmissivity, tr, mlx90640To);
    MLX90640_BadPixelsCorrection((&mlx90640)->brokenPixels, mlx90640To, 1, &mlx90640);
    MLX90640_BadPixelsCorrection((&mlx90640)->outlierPixels, mlx90640To, 1, &mlx90640);
    //HAL_Delay(16);
    /* USER CODE END WHILE */

    /* USER CODE BEGIN 3 */

  }
  /* USER CODE END 3 */
}

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
/* USER CODE BEGIN 4 */


/**
  * @brief  Compares two buffers.
  * @param  pBuffer1, pBuffer2: buffers to be compared.
  * @param  BufferLength: buffer's length
  * @retval 0  : pBuffer1 identical to pBuffer2
  *         >0 : pBuffer1 differs from pBuffer2
  */
static uint16_t Buffercmp(uint8_t *pBuffer1, uint8_t *pBuffer2, uint16_t BufferLength)
{
  while (BufferLength--)
  {
    if ((*pBuffer1) != *pBuffer2)
    {
      return BufferLength;
    }
    pBuffer1++;
    pBuffer2++;
  }

  return 0;
}

/* USER CODE END 4 */
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


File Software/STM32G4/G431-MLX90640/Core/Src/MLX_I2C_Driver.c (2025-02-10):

#include "MLX90640_I2C_Driver.h"
#include "stm32g4xx_hal.h"

extern I2C_HandleTypeDef hi2c2;

void MLX90640_I2CInit()
{
    return;
}

int MLX90640_I2CGeneralReset(void)
{
    return 0;
}

int MLX90640_I2CRead(uint8_t slaveAddr, uint16_t startAddress, uint16_t nMemAddressRead, uint16_t* data)
{
    // Data buffer, we will read the raw bytes here before processing them (nMemAddressRead * 2 bytes)
    uint8_t* p = (uint8_t*)data;

    // Use HAL's built-in I2C memory read function, which handles both address and data transmission.
    // This will read nMemAddressRead 16-bit words into the buffer p.
    if (HAL_I2C_Mem_Read(&hi2c2, (slaveAddr << 1), startAddress, I2C_MEMADD_SIZE_16BIT, p, nMemAddressRead * 2, HAL_MAX_DELAY) != HAL_OK)
    {
        return -1;  // Return -1 if the communication fails (NACK or other issue)
    }

    // Ensure the I2C bus is ready before proceeding
    //while (HAL_I2C_GetState(&hi2c2) != HAL_I2C_STATE_READY) {}

    // Post-process the data to restore the correct endianness
    // MLX90640 returns data in LSByte-first format, so we need to swap the bytes.
    for (int i = 0; i < nMemAddressRead * 2; i += 2)
    {
        uint8_t tempBuffer = p[i + 1];
        p[i + 1] = p[i];
        p[i] = tempBuffer;
    }

    return 0;  // Return 0 if successful
}

int MLX90640_I2CWrite(uint8_t slaveAddr, uint16_t writeAddress, uint16_t data)
{
    uint8_t cmd[2];
    static uint16_t datacheck;

    // Prepare the 16-bit data in LSByte-first format, as required by the MLX90640.
    cmd[0] = data >> 8;  // MSByte first
    cmd[1] = data & 0x00FF;  // LSByte second

    // Use HAL's I2C memory write function to write the data.
    // This function handles the address and the data in one transaction.
    if (HAL_I2C_Mem_Write(&hi2c2, slaveAddr << 1, writeAddress, I2C_MEMADD_SIZE_16BIT, cmd, 2, 1000) != HAL_OK)
    {
        return -1;  // Return -1 if there was a NACK or communication failure
    }

    // Verify the data by reading it back and checking if the written data matches the read data.
    MLX90640_I2CRead(slaveAddr, writeAddress, 1, &datacheck);
    if (datacheck != data)
    {
        return -2;  // Return -2 if the data verification failed
    }

    // Ensure the I2C bus is ready before allowing other operations
    //while (HAL_I2C_GetState(&hi2c2) != HAL_I2C_STATE_READY) {}

    return 0;  // Return 0 if successful
}

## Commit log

2024-07-14 added a testing folder to begin writing I2C drivers for IR temp and accel, fixed CAN to have extended ID
    [main.c, stm32f103.ioc]
2024-07-15 added uart abstraction in examples/Testing
    [gr25_nodes.kicad_sch]
2024-09-29 some chnages, for tracking purpose
    [gr25_nodes.kicad_pcb, gr25_nodes.kicad_sch]
2024-09-29 added some v3 work, mostly stlink on pcb and power stuff on main MCU
    [Bootloader.kicad_sch, Main_MCU.kicad_sch, Power.kicad_sch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]
2024-09-30 a lot of progress on V3, still need to test if bootloader works
    [Bootloader.kicad_sch, Main_MCU.kicad_sch, Power.kicad_sch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]
2024-09-30 sync update
    [Bootloader.kicad_sch, Main_MCU.kicad_sch, Power.kicad_sch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]
2024-09-30 finished v3, need to fix drc silkscreens
    [Bootloader.kicad_sch, Main_MCU.kicad_sch, gr25_nodes.kicad_pcb]
2024-10-01 DRC no error. GOOD. quick sync too.
    [Main_MCU.kicad_sch, gr25_nodes.kicad_pcb]
2024-10-01 finished the thing, need to optimize bom a little bit. need to flip some of the components too
    [Bootloader.kicad_sch, Power.kicad_sch, bom.csv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]
2024-10-02 alt placement made
    [Bootloader.kicad_sch, Main_MCU.kicad_sch, Power.kicad_sch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]
2024-10-02 rerouted a little and added swo
    [Bootloader.kicad_sch, Main_MCU.kicad_sch, bom.csv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]
2024-10-02 some alt placement finished, moved xtal. will branch and rotate stlink by 90
    [Bootloader.kicad_sch, Main_MCU.kicad_sch, gr25_nodes.kicad_pcb]
2024-10-03 fixed placement, added some decals, now using clock from stlink
    [Bootloader.kicad_sch, Main_MCU.kicad_sch, Power.kicad_sch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]
2024-10-04 flipped GND and 3v3 layer
    [gr25_nodes.kicad_pcb]
2025-01-13 fixed the CAN issue and rerouted some things. Added a solder bridge for Vref so that there is a choice of using it or not.
    [Main_MCU.kicad_sch, Power.kicad_sch, Strain Guages.kicad_pcb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]
2025-01-15 redud some of the zones and changed the thermal relief to not be traces but filled zones
    [gr25_nodes.kicad_pcb]
2025-01-26 changed the order of some folders and added current working folder
2025-01-30 redid two traces, changed data
    [gr25_nodes.kicad_pcb]
2025-02-10 changed some gitignore stuff and added MLX and BMI sub folders for the g431 and teensy respectively
    [bom.csv, designators.csv, gr25_nodes_panelized.kicad_pcb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]
2025-02-22 working spi DMA under TCM-CAN, start of the project testing for ICANSPI
2025-02-23 ICANSPI working ish need to test with higher SPI speeds and then write code for jetson
2025-04-08 V3.2 SAM Board added, CHASSES TOF code added and some TCM-CAN stuff added
    [Main_MCU.kicad_sch, gr25_nodes.kicad_pcb]
2025-04-12 added TCM-CAN link work
    [TCM-CAN.kicad_pcb, TCM-CAN.kicad_sch]
2025-04-12 tcm can schematic done, only needs to be routed
    [Bootloader.kicad_sch, Main_MCU.kicad_sch, Power.kicad_sch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]
2025-04-17 bug fix
    [TCM-CAN.kicad_pcb, TCM-CAN.kicad_sch, gr25_nodes.kicad_pcb]
2025-04-17 started work on the PCB for TCM-CAN
    [TCM-CAN.kicad_pcb, TCM-CAN.kicad_sch]
2025-04-19 Finished TCM-CAN pcb need to order it and get it drc'd
    [TCM-CAN.kicad_pcb, TCM-CAN.kicad_sch]
2025-04-22 tcm-can pcb done
    [TCM-CAN.kicad_pcb, TCM-CAN.kicad_sch, bom.csv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]
2025-04-22 fixed pin names
    [Main_MCU.kicad_sch, TCM-CAN.kicad_pcb, gr25_nodes.kicad_pcb]
2025-04-22 added pin numbers
    [gr25_nodes.kicad_pcb]
2025-04-25 added a neopixel and moved some pins around
    [Main_MCU.kicad_sch, TCM-CAN.kicad_pcb, gr25_nodes.kicad_pcb]
2025-05-20 SAM V3.3 I think correct push
    [Main_MCU.kicad_sch, gr25_nodes.kicad_pcb]
2025-05-24 sync + load
    [gr25_nodes.kicad_pcb]

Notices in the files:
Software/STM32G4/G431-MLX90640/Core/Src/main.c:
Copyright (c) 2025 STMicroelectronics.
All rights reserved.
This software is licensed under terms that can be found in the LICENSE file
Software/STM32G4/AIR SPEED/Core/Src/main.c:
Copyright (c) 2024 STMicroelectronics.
